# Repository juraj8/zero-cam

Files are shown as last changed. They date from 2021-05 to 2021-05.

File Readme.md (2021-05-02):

# Zero Cam





Zero Cam is open security camera based on Raspberry Pi Zero. This solution should be an alternative to low cost IP cameras.
One advantage is upgradeability of software running the camera is that it always can be updated to add support to various technologies, which cannot be achieved with other cheap cameras.

## Features 

* Ethernet 100/10 BaseT with passive POE
* IR light for night vision,
* Temperature and humanity sensor,
* Can be powered by external DC powerfully 24~48V
* Can use any Raspberry Pi compatible camera module.

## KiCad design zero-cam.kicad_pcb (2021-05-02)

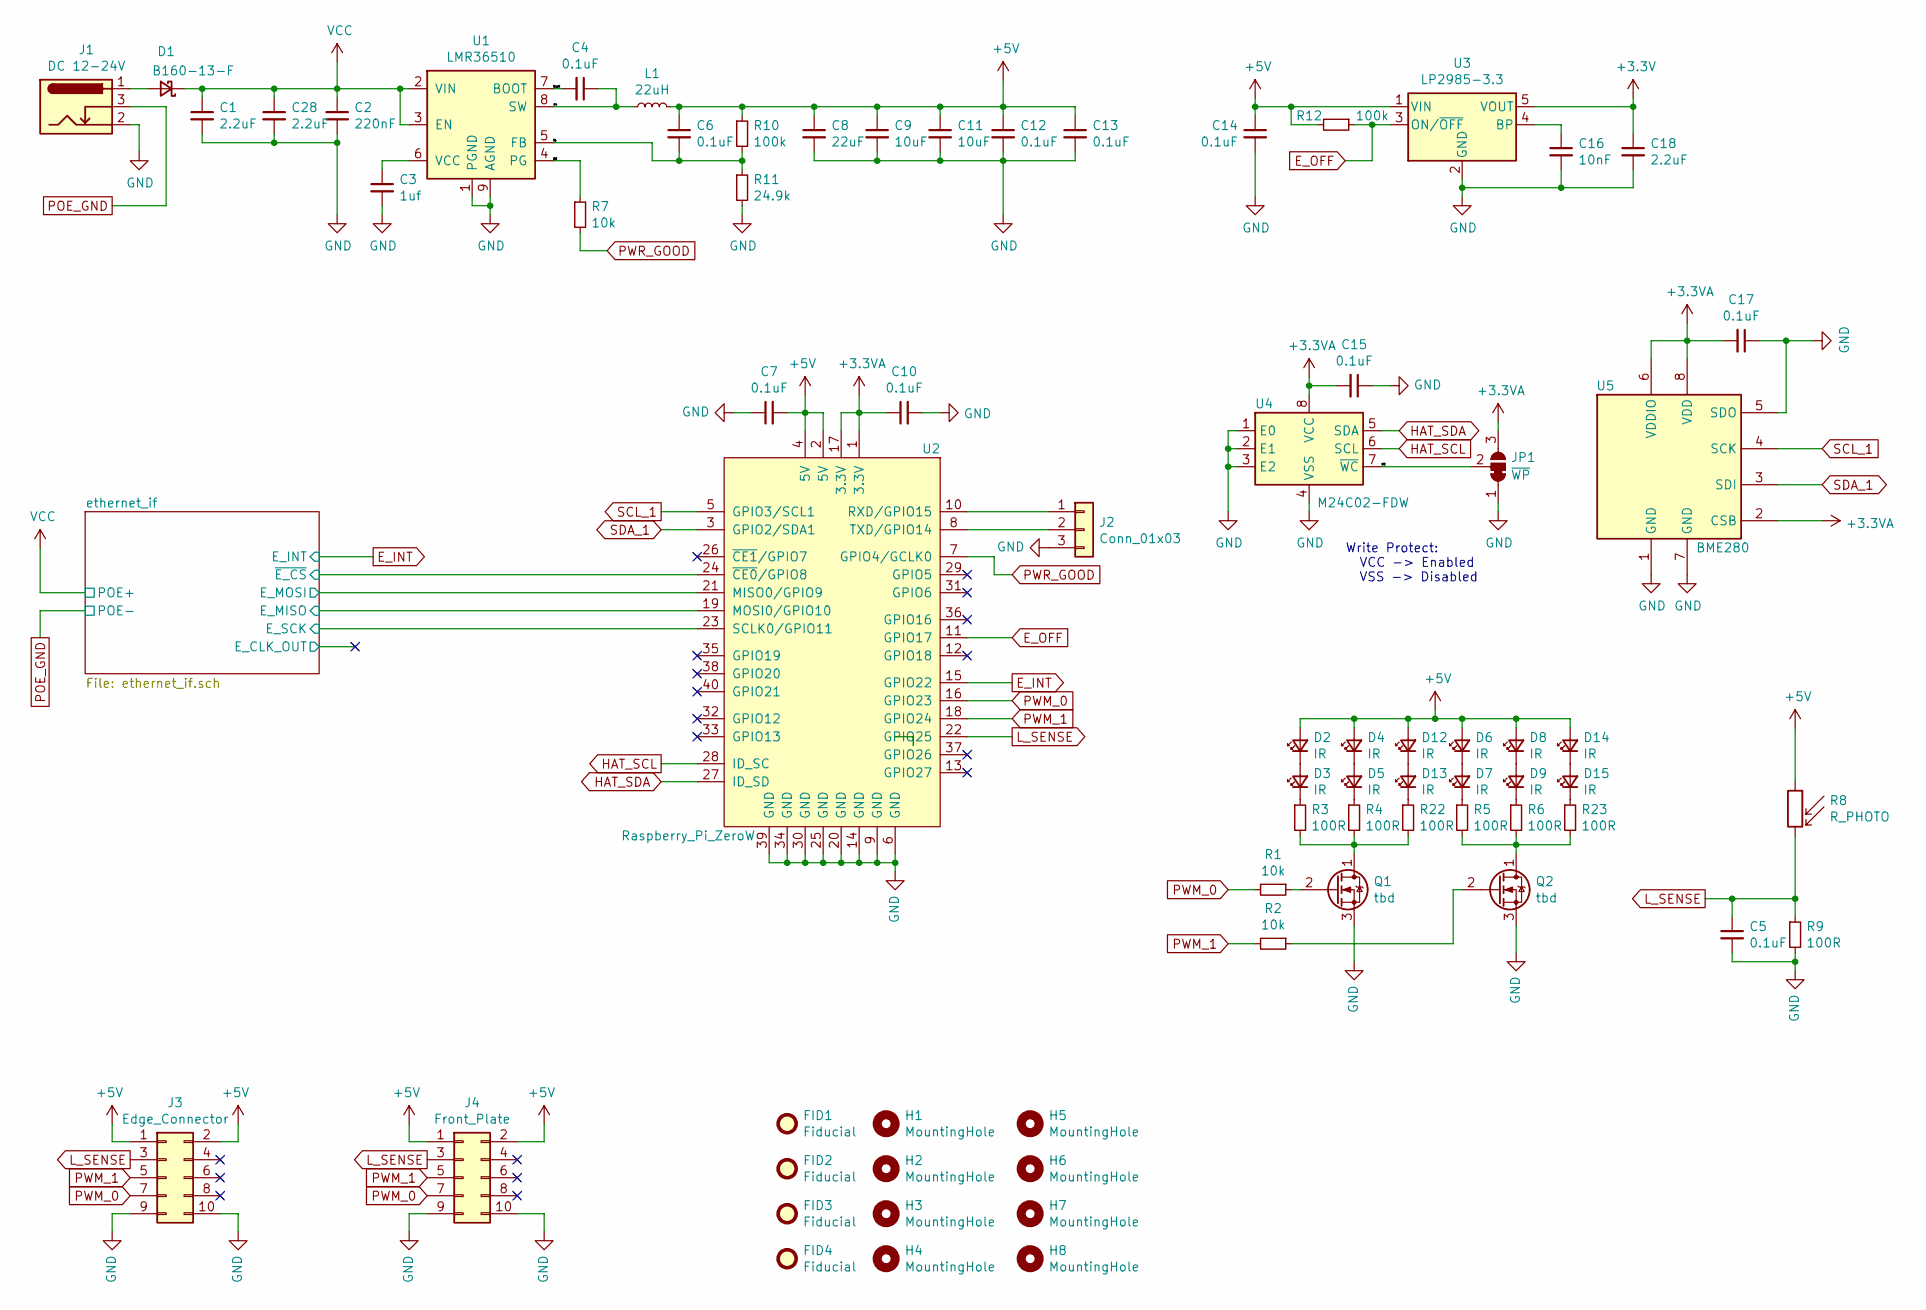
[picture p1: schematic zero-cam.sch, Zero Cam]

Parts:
C1, C28: 2.2uF; C_1210_3225Metric_Pad1.33x2.70mm_HandSolder
C2: 220nF; C_0805_2012Metric_Pad1.18x1.45mm_HandSolder
C3: 1uf; C_0805_2012Metric_Pad1.18x1.45mm_HandSolder
C4, C5, C6, C7, C10, C12, C14, C15, C17: 0.1uF; C_0805_2012Metric_Pad1.18x1.45mm_HandSolder
C8: 22uF; C_1206_3216Metric_Pad1.33x1.80mm_HandSolder
C9, C11: 10uF; C_1206_3216Metric_Pad1.33x1.80mm_HandSolder
C13: 0.1uF; C_0603_1608Metric_Pad1.08x0.95mm_HandSolder
C16: 10nF; C_0805_2012Metric_Pad1.18x1.45mm_HandSolder
C18: 2.2uF; C_0805_2012Metric_Pad1.18x1.45mm_HandSolder
D1: B160-13-F; D_SMA_Handsoldering
D2, D3, D4, D5, D6, D7, D8, D9, D12, D13, D14, D15: IR; LED_0805_2012Metric_Pad1.15x1.40mm_HandSolder
FID1, FID2, FID3, FID4: Fiducial; Fiducial_0.5mm_Mask1mm
H1, H2, H3, H4, H5, H6, H7, H8: MountingHole; MountingHole_3.2mm_M3_DIN965
J1: DC 12-24V; BarrelJack_Horizontal
J2: Conn_01x03; PinHeader_1x03_P2.54mm_Vertical
J3: Edge_Connector; Edge_PinHeader_2x05_P2
J4: Front_Plate; PinSocket_2x05_P2.54mm_Vertical
JP1: ~WP~; SolderJumper-3_P1.3mm_Bridged12_RoundedPad1.0x1.5mm_NumberL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
L1: 22uH; L_10.4x10.4_H4.8
Q1, Q2: tbd; TSOT-23
R1, R2, R7: 10k; R_0805_2012Metric_Pad1.20x1.40mm_HandSolder
R3, R4, R5, R6, R9, R22, R23: 100R; R_0805_2012Metric_Pad1.20x1.40mm_HandSolder
R8: R_PHOTO; R_LDR_4.9x4.2mm_P2.54mm_Vertical
R10, R12: 100k; R_0805_2012Metric_Pad1.20x1.40mm_HandSolder
R11: 24.9k; R_0805_2012Metric_Pad1.20x1.40mm_HandSolder
U1: LMR36510; Texas_HSOP-8-1EP_3.9x4.9mm_P1.27mm_ThermalVias
U2: Raspberry_Pi_ZeroW; Raspberry_Pi_Zero_Socketed_THT_FaceDown_MountingHoles
U3: LP2985-3.3; SOT-23-5
U4: M24C02-FDW; TSSOP-8_4.4x3mm_P0.65mm
U5: BME280; Bosch_LGA-8_2.5x2.5mm_P0.65mm_ClockwisePinNumbering

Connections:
+3.3VA: C10.1, C15.2, C17.2, JP1.3 (B), U2.1 (3.3V), U2.17 (3.3V), U4.8 (VCC), U5.2 (CSB), U5.6 (VDDIO), U5.8 (VDD)
+3V3: C18.1, U3.5 (VOUT); also elsewhere on the board
+5V: C6.1, C7.2, C8.1, C9.1, C11.1, C12.1, C13.1, C14.1, D2.2 (A), D4.2 (A), D6.2 (A), D8.2 (A), D12.2 (A), D14.2 (A), J3.1, J3.2, J4.1, J4.2, L1.2, R8.1, R10.1, R12.2, U2.2 (5V), U2.4 (5V), U3.1 (VIN)
/WC: JP1.2 (C), U4.7 (~WC)
/boot: C4.2, U1.7 (BOOT)
/ethernet_if/E_MISO: U2.19 (MOSI0/GPIO10); also elsewhere on the board
/ethernet_if/E_MOSI: U2.21 (MISO0/GPIO9); also elsewhere on the board
/ethernet_if/E_SCK: U2.23 (SCLK0/GPIO11); also elsewhere on the board
/ethernet_if/~E_CS~: U2.24 (~CE0~/GPIO8); also elsewhere on the board
/fb: C6.2, R10.2, R11.1, U1.5 (FB)
/pg: R7.1, U1.4 (PG)
/sw: C4.1, L1.1, U1.8 (SW)
E_INT: U2.15 (GPIO22); also elsewhere on the board
E_OFF: R12.1, U2.11 (GPIO17), U3.3 (ON/~OFF~)
GND: C1.2, C2.2, C3.2, C5.2, C7.1, C8.2, C9.2, C10.2, C11.2, C12.2, C13.2, C14.2, C15.1, C16.2, C17.1, C18.2, C28.2, J1.2, J2.3, J3.9, J3.10, J4.9, J4.10, JP1.1 (A), Q1.3 (S), Q2.3 (S), R9.2, R11.2, U1.1 (PGND), U1.9 (AGND), U2.6 (GND), U2.9 (GND), U2.14 (GND), U2.20 (GND), U2.25 (GND), U2.30 (GND), U2.34 (GND), U2.39 (GND), U3.2 (GND), U4.1 (E0), U4.2 (E1), U4.3 (E2), U4.4 (VSS), U5.1 (GND), U5.5 (SDO), U5.7 (GND); also elsewhere on the board
HAT_SCL: U2.28 (ID_SC), U4.6 (SCL)
HAT_SDA: U2.27 (ID_SD), U4.5 (SDA)
L_SENSE: C5.1, J3.3, J4.3, R8.2, R9.1, U2.22 (GPIO25)
unnamed: C3.1, U1.6 (VCC)
unnamed: C16.1, U3.4 (BP)
unnamed: D1.2 (A), J1.1
unnamed: D2.1 (K), D3.2 (A)
unnamed: D3.1 (K), R3.1
unnamed: D4.1 (K), D5.2 (A)
unnamed: D5.1 (K), R4.1
unnamed: D6.1 (K), D7.2 (A)
unnamed: D7.1 (K), R5.1
unnamed: D8.1 (K), D9.2 (A)
unnamed: D9.1 (K), R6.1
unnamed: D12.1 (K), D13.2 (A)
unnamed: D13.1 (K), R22.1
unnamed: D14.1 (K), D15.2 (A)
unnamed: D15.1 (K), R23.1
unnamed: J2.1, U2.10 (RXD/GPIO15)
unnamed: J2.2, U2.8 (TXD/GPIO14)
unnamed: Q1.1 (D), R3.2, R4.2, R22.2
unnamed: Q1.2 (G), R1.1
unnamed: Q2.1 (D), R5.2, R6.2, R23.2
unnamed: Q2.2 (G), R2.1
POE+: C1.1, C2.1, C28.1, D1.1 (K), U1.2 (VIN), U1.3 (EN); also elsewhere on the board
POE-: J1.3; also elsewhere on the board
PWM_0: J3.7, J4.7, R1.2, U2.16 (GPIO23)
PWM_1: J3.5, J4.5, R2.2, U2.18 (GPIO24)
PWR_GOOD: R7.2, U2.7 (GPIO4/GCLK0)
SCL_1: U2.5 (GPIO3/SCL1), U5.4 (SCK)
SDA_1: U2.3 (GPIO2/SDA1), U5.3 (SDI)

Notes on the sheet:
Write Protect: VCC -> Enabled VSS -> Disabled

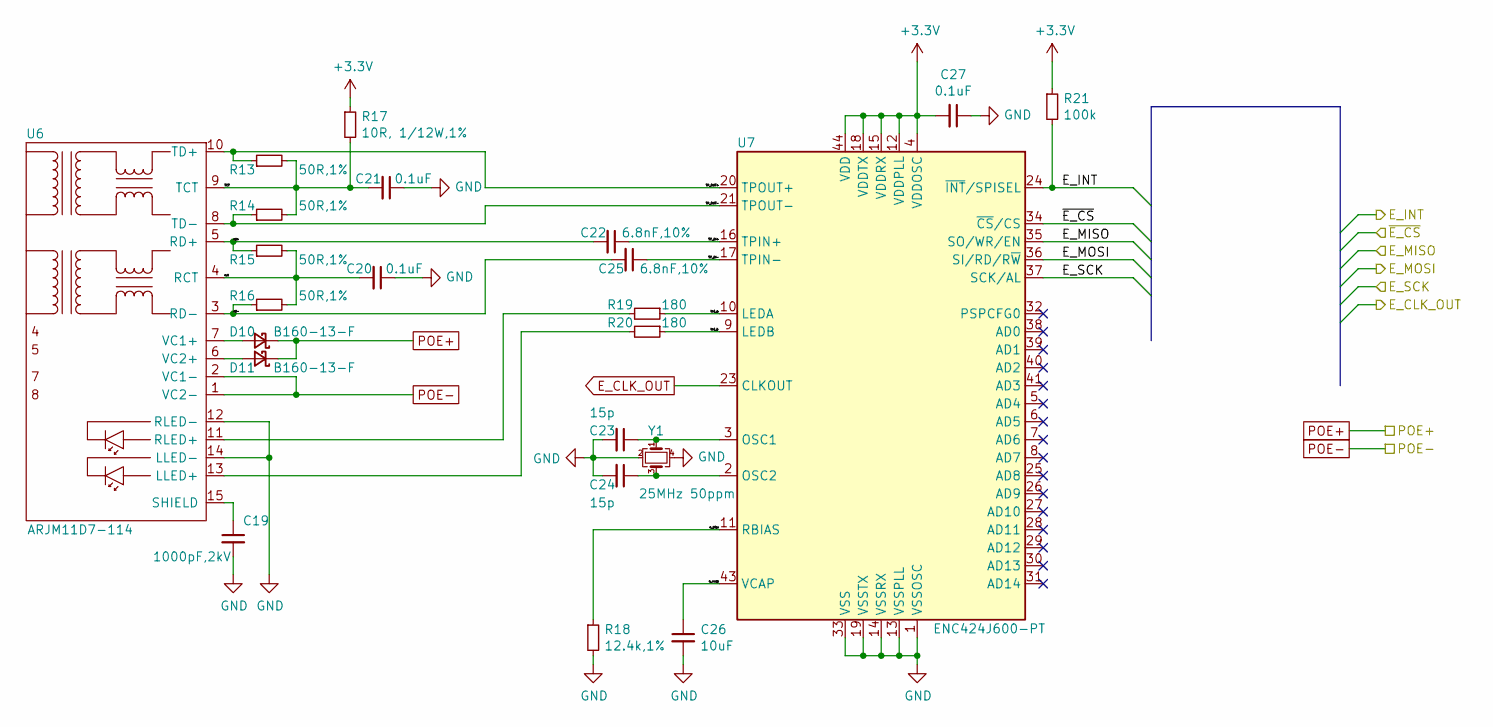
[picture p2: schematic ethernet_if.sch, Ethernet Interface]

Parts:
C19: 1000pF,2kV; C_0805_2012Metric_Pad1.18x1.45mm_HandSolder
C20, C21, C27: 0.1uF; C_0805_2012Metric_Pad1.18x1.45mm_HandSolder
C22, C25: 6.8nF,10%; C_0805_2012Metric_Pad1.18x1.45mm_HandSolder
C23, C24: 15p; C_0805_2012Metric_Pad1.18x1.45mm_HandSolder
C26: 10uF; C_0805_2012Metric_Pad1.18x1.45mm_HandSolder
D10, D11: B160-13-F; D_SMA_Handsoldering
R13, R14, R15, R16: 50R,1%; R_0805_2012Metric_Pad1.20x1.40mm_HandSolder
R17: 10R, 1/12W,1%; R_0805_2012Metric_Pad1.20x1.40mm_HandSolder
R18: 12.4k,1%; R_0805_2012Metric_Pad1.20x1.40mm_HandSolder
R19, R20: 180; R_0805_2012Metric_Pad1.20x1.40mm_HandSolder
R21: 100k; R_0805_2012Metric_Pad1.20x1.40mm_HandSolder
U6: ARJM11D7-114
U7: ENC424J600-PT; TQFP-44_10x10mm_P0.8mm
Y1: 25MHz 50ppm; Crystal_SMD_3225-4Pin_3.2x2.5mm_HandSoldering

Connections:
+3V3: C27.2, R17.1, R21.1, U7.4 (VDDOSC), U7.12 (VDDPLL), U7.15 (VDDRX), U7.18 (VDDTX), U7.44 (VDD); also elsewhere on the board
/ethernet_if/E_MISO: U7.35 (SO/WR/EN); also elsewhere on the board
/ethernet_if/E_MOSI: U7.36 (SI/RD/R~W); also elsewhere on the board
/ethernet_if/E_SCK: U7.37 (SCK/AL); also elsewhere on the board
/ethernet_if/TCT: C21.2, R13.2, R14.2, R17.2, U6.9 (TCT)
/ethernet_if/TP_IN+: C22.1, U7.16 (TPIN+)
/ethernet_if/TP_IN-: C25.1, U7.17 (TPIN-)
/ethernet_if/TP_OUT+: R13.1, U6.10 (TD+), U7.20 (TPOUT+)
/ethernet_if/TP_OUT-: R14.1, U6.8 (TD-), U7.21 (TPOUT-)
/ethernet_if/e_bias: R18.1, U7.11 (RBIAS)
/ethernet_if/e_vcap: C26.1, U7.43 (VCAP)
/ethernet_if/led_a: R19.1, U7.10 (LEDA)
/ethernet_if/led_b: R20.1, U7.9 (LEDB)
/ethernet_if/rct: C20.2, R15.2, R16.2, U6.4 (RCT)
/ethernet_if/rd+: C22.2, R15.1, U6.5 (RD+)
/ethernet_if/rd-: C25.2, R16.1, U6.3 (RD-)
/ethernet_if/~E_CS~: U7.34 (~CS~/CS); also elsewhere on the board
E_CLK_OUT: U7.23 (CLKOUT)
E_INT: R21.2, U7.24 (~INT~/SPISEL); also elsewhere on the board
GND: C19.2, C20.1, C21.1, C23.2, C24.2, C26.2, C27.1, R18.2, U6.12 (RLED-), U6.14 (LLED-), U7.1 (VSSOSC), U7.13 (VSSPLL), U7.14 (VSSRX), U7.19 (VSSTX), U7.22 (VSSTX), U7.33 (VSS), U7.42 (VSS), Y1.2, Y1.4; also elsewhere on the board
unnamed: C19.1, U6.15 (SHIELD)
unnamed: C23.1, U7.3 (OSC1), Y1.1
unnamed: C24.1, U7.2 (OSC2), Y1.3
unnamed: D10.2 (A), U6.7 (VC1+)
unnamed: D11.2 (A), U6.6 (VC2+)
unnamed: R19.2, U6.11 (RLED+)
unnamed: R20.2, U6.13 (LLED+)
POE+: D10.1 (K), D11.1 (K); also elsewhere on the board
POE-: U6.1 (VC2-), U6.2 (VC1-); also elsewhere on the board

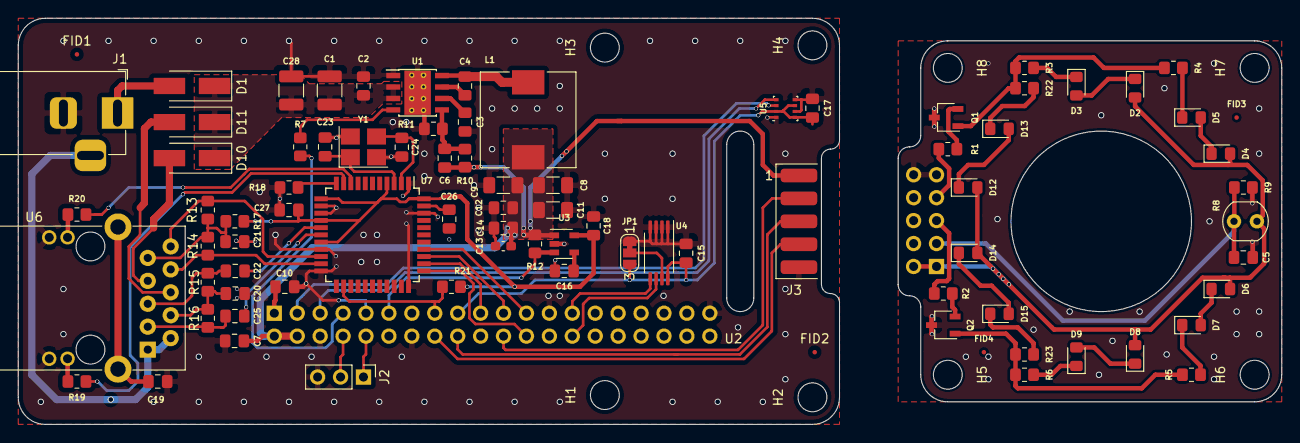
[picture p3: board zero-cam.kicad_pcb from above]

Board: 2 copper layers, 140.0 x 45.0 mm, 94 parts (1 on the bottom side), 65 nets.

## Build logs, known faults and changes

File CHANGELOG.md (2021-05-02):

# Changelog

## v0.2.0 (02.05.2021)

- initial release.
- ethernet interface with POE.
- IR front face board.
- Power management.

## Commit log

2021-04-25 Schematic rc1 finished.
    [ethernet_if.sch, zero-cam.sch]
2021-04-25 Added pcb file.
    [ethernet_if.sch, zero-cam.kicad_pcb]
2021-04-27 Change for actual footprints, raff board done.
    [ethernet_if.sch, zero-cam.kicad_pcb, zero-cam.sch]
2021-04-29 Connector placment done, dimentions decided ...
    [ethernet_if.sch, zero-cam.kicad_pcb, zero-cam.sch]
2021-04-30 start layout
    [zero-cam.kicad_pcb, zero-cam.sch]
2021-05-01 Layout almost done
    [ethernet_if.sch, zero-cam.kicad_pcb, zero-cam.sch]
2021-05-02 Release v0.2.0
    [ethernet_if.sch, zero-cam.kicad_pcb, zero-cam.sch]
